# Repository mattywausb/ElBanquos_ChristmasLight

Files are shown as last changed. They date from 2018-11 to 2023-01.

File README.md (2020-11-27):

# ElBanquos Christmas Lights
An Ardiuno project using Neopixels to create slowly changing christmas light pictures in my window.

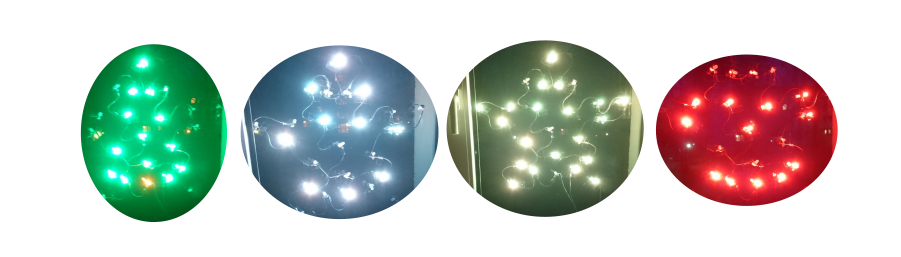
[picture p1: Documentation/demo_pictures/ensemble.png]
demo_ensemble some Impressions


## Whats the idea ?
I like to amaze people with riddles and small wonders. My favourinte approach is to establish little miracles that can only be noticed by people that observe the world carefully (its not for the 7x24 smartphone viewers). A long term vision was doing this with christmas decoration lights that change their pattern or picture without attracting attention by blinking or fast changing colors.

People should see the picture in the window and next time they come by will see another picture. They may wonder if they remembered it correctly or they might think that the guy behind the window changes it manually every day.  Only if they watch long enough they will see, how the pattern of light evolves slowly from one picture to another. Maybe they get curious enough to wait, what picture will come next and if they have seen them all.

Since there is not programmable christmas light chain in the stores, I have built my own.

### And the fireworks ?
While also enjoing it on new years eve I had the idea of switching the concept of slow animation to fast firework like effects to celebrate the new year. So I added a countdown clock and some fireworks animations. This mode can be activated for that special day.

## Features
* Easy maintainable programming of the light patterns
  * Picture is described on a logical lamp arrangemant. Translation to physical arrangement on the window is done at runtime.
  * Colorpalette helps to keep colors conistent an save memory.
  * Pixels can be distributed over multiple chains but appear in a linear adressspace
* Randomized transformation from one picture to the next
  * Random next picture
  * Random transformation order and timing of the pixels
  * Asynchronous and overlapping transformation of the pixels
  * Random hold time for one picture
* Fireworks for new years eve
  * countdown clock (mostly slow animated)
  * multiple simulations of fireworks
  * modularized and extendable implementation (add new ideas in 30 minutes)
* Testmodes to check 
  * correct pixel position
  * Pictures
  * Pixelfunction

## Whats in this repository
* Ardunio sketches for testing pixels and the final application
* Inkscape SVG with my light arrangement with 24 lamps 
* Fritzing circuit documentation
* Pictures of different assembly state phases to give you an idea how to build the chains
* [manual] (Documentation/manual_en.md) 

## Hardwarelist
* Arduino Uno board (or anything similar with 5 Digital Outs and 2 KByte SRAM)
* 24 Neopixel 8 mm throughole LED (or more)
* enough 3 core cable that is flexible and as thin as possible (I used old USB mouse wire, white = data, red+green=+5V, black+ground=gound)
* enough prototype PCB to cut the small connection pcb for every lamp
* 2 buttons
* whires 
* small breadboard (I used the Uno starterkit)
* "sugru" glue clay to protect the led mounting PCB's
* powert supply 5V / 1,5 A (for 24 pixels)
* scotchtape

## Softwarelist
* Arduino 
* Neo Pixel Library
* Fritzing (optional)
* Inkscape (optional)

## Tools
* Soldering iron 
* soldering holder
* wire stripper for very small diameters
* wire cutter
* pcb cutting tool (I used a saw)

## Main steps to build
* Assemble test circuit on the breadboard
* Test LED's on the breadboard (up to 8 when using 5V Adrunio board power)
* assemble every chain
  * Cut the small PCB boards (1 for the plug and 1 for every lamp)
  * Cut the mouse cable an remove isolations (1 for every lamp, 1st should be longer to reach from the window to the uno)
  * Create a 3 pin plug at one end of the long whire
  * Add pcb/Neopixel and continuation whire as often as needed (I made 3 chains of 8 pixels)
### Build effort
Initial time is needed to set up the uno and breadboard for testing.
After getting into a stable workflow it took me about 10 Minutes for every lamp (Cut pcb, cut cable, solder lamp, test). So all in all 240 Minutes for 24 Lamps (4 Hours) for assembling the chains. With better soldering technique and tools this might get better.

### Main material costs 43 EUR
* roundabout 25 Euro for 25 Neopixels (I killed one by testing with wrong polarity, thats why i have only 24)
* 8 Euros for the Sugru Glue Clay (1 Package with 3 portions)
* Old usb mouse cables should be available at every flea market
* My dedicated power supply const 10 Eur but mostly you already have some in stock

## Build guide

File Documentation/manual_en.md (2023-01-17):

# ElBanquos Christmas Lights - Manual

## Functions
The system contains multiple programs, that can be accessed by using the two buttons:
* Mode
* Step
 
Especially for assembly and installation there are various test programs to verify the electrical function and the correct arrangement of the lamps.

### Comprehensive mode change table:

|Current Mode|Press "Mode"|Press "Step"|Hold "Mode" Long|Hold "Step" Long|
|---|---|---|---|---|
|Show|>Countdown|>Transition||
|Transition|>Countdown|>Show||
|Countdown|>Fireworks|>Set Hour||
|Set Hour|Hour down|Hour up||>Set Minute|
|Set Minute|Minute down|Minute up||>Countdown|
|Fireworks|>Show|Next Effect|>Sensor Calibration||
|Sensor Calibration|>Show|>Tst: Placement|||
|Tst: Placement|>Tst: Palette|Switch Lamp group||
|Tst: Palette|>Tst: Pictures|Switch color of inner lamps||
|Tst: Picture|Previous Picture|Next Picture|>Tst: Fade Solo||
|Tst: Fade Solo|>Tst: Fade Ensemble|Next Lamp||
|Tst: Fade Ensemble|>Tst: Scaling|Next Lamp||
|Tst: Scaling Current|>Show|Add Lamp||

## Components and setup

* LED Light chains (currently 3 chains with 8 lamps each)
* controller board with
   * arduino
   * connectors for the light chains
   * Buttons
   * light sensor
   * light threshold control
   * USB Power cable Plug (Delivers power only, not data of arduino)
* USB Power Supply (5 V with at least 1.5 A)

This will not work with USB power supplies, which provide higher current only after been requested. (most USB power supplies don't care)

Maximum power consumption: LEDS (24x60mA) + Controllerboard (80mA) = 1.5 A 

## Setup
* Position light chains on the window
* connect light chains to controller board
* connect power

Never connect/disconnect light chains, when board has power. After disconnect from power, wait 1 Minute until connectin/disconnecting the light chains. This guarantees full discarge of the controller boards buffer 1000uF capacitor.

After connecting, check out the Testprogramm

## Mode descriptions

### Show Mode (Default Mode when switched on)
The show mode shows the static picture for a random number of seconds. After the wait time is over, a random new picture is determined and the program switches to transition mode.

Press MODE-> Countdown Mode

Press STEP-> Start transition to next picture in list

#### Daylight detection
The show mode uses a photocell to detect the ambient light situation. Only during low light, the show mode will choose one of the normal pictures. During "dailight", the show mode will activate one single lamp as an power indicator.

The threshold to determine "dailight" is set by the potentiometer. For adustment see Tst: Light sensor calibration.
When in daylight opreration, the sensor will be checked for a change every 60 seconds.

### Transition Mode
The Transition Mode modifies the lamps slowly in random order to transition to the next picture. After it is done, the mode switches to Show Mode.

Press MODE->  Countdown Mode

Press STEP-> Foreward transition to target picture an switch to show mode. 

### Countdown Mode
The Countdown Mode will display time of an internal clock and switch to fireworks automatically at 00:00. 
To understand the time display, see description "Hot the countdown time is displayed" below or check the table on the userpanel.

Press MODE-> Switch to Fireworks (Will be done automatically when reaching 00:00:00)

Press STEP-> Switch to Set Hour

### Set Hour Mode
The Set Hour Mode is used to set the hours left of the countdown. 

During the Set Hour Mode, the center lamp is **blinking red**

Press MODE-> 1 Hour Backward

Press STEP-> 1 Hour Forward

STEP Hold 2 sec (center lamp turns white) and release: Switch to Set Minute Mode

### Set Minute Mode
The Set Minute Mode is used to set the minutes left of the countdown. 
During the Set Hour Mode, the center lamp is **blinking blue**

Press MODE-> 1 Minute Backward

Press STEP-> 1 Minute Forward

Hold STEP for at least 2 sec (center lamp turns white): The release will start Clock (with 0 Seconds) and switch to Countdown Mode

### Fireworks Mode
The Fireworks Mode plays randomly chosen firework animations

Press MODE-> Switch to Show Mode

Press STEP-> Change to next fireworks pattern

MODE Hold 2 sec and release: Switch to Sensor Calibration

### Sensor Calibration
Sensor calibration activates most of the lamps in white and display the 
deviation between the current light sensor value and the threshold as a red lamp. 
The scale is formed by lamps E,10,K,11,A,1,G,2,8 (See user panel for lamp identification). The middle lamp on the star tip (A),
represents the current sensor value. The red indicated postion shows the current threshold, 
defined by the user setting. Placing the threshold to the left (E,10,K,11) defines the current
sensor value as lowlight. Setting it to the right (1,G,2,B) , defines the current sensor value as daylight.
One lamp stands for one histeresys interval. 
Value changes inside the histeresys interval will not change the current low/day state. 
To adjust the threshold for a spefic light level, wait for the level to come up and place the red dot 
in the center (A).

Press MODE -> Switch to Placement Test

Press STEP -> Switch to Show Mode

This calibration mode is only for easy search of the threshold.  The setting of the threshold is measured independently at every change of a picture, 
so adjustments are accepted, event  without using this mode.

Also be shure to place the sensor in a, it is not affected by the light of the christmas pictures. To help you
when tracing he path of the light, this mode switches most of the lights to white.
Placing some shade over the sensor, might be necessary. If the light of the pictures can reach the sensor,
some pitures might be bright enough to trigger the day mode.

### Placement Test
The placement test shows a rainbow color pattern on the different groups of lamps:

Press MODE-> Switch to Palette Test

Press STEP-> Switch to next group

The groups are:
* Chain identification: Three lamps in the center should be red,green,blue from left to right (if not you might have swapped cables when plugging)
* outer Pentagon/Star tips: Red on 12 o'clock, going clockwise to yellow, green, cyan, blue
* Middle circle: Red on 12 o'clock, going clockwise to yellow, green, cyan, blue (the 2nd lamp of a pair will be brighter)
* Inner Pentagon: Red on 6 o'clock, going clockwise to yellow, green, cyan, blue
* Bottom: Red, Middle yellow, "Head left" green, "Head right" blue

Should this be mixed up you need to check cables or placement of the lamps

### Palette Test
The palette test shows every palette color on a single lamp (Starting with lamp 6), and allows swithching through all palette colors on the inner ring and center lamp.

Press MODE-> Switch to Picture Test

Press STEP-> Switch inner lamps to next palette color

### Picture Test
The Picture Test shows a picture until it is stopped.

Press MODE-> Switch to Fade Solo Test

Press STEP-> Switch to next picture

Hold MODE for 2 Seconds -> Swith to Fade Solo Test

### Fade Solo Test
The Fade Solo Test fades one lamp fading green value from 0 to 255. Should be used while assembling the chain, to test added lamps.

Press MODE-> Switch to Fade Ensemble Test

Press STEP-> Switch to next lamp in the physical chain

### Fade Ensemble Test
The Fade Ensemble Test lights all lamps in cyan and a selected lamp with a fading red. Should be used while assembling the chain, to approve conductivity.

Press MODE-> Switch to Scaling Test

Press STEP-> Switch to next lamp in physical chain

### Scaling Current Test
The scaling current test lights lamps in with fading white, starting with one lamp. 
Should be used to check, if assemble cables and power supply will provide enough current. 
When all lamps are running, you have reached the highest power consumption possible. 
Fading must still be smooth and steady on all lamps an the should be no change in the white color. 
(When white is getting warmer, this indicates unsufficient power)

Press MODE-> Switch to Show Mode

Press STEP-> Add next lamp in physical chain.

# How the countdown time is displayed
The time display is designed to appear very static and add more movement, the nearer the time is to 00:00 resulting in a 1 Minute Countdown at 23:59.
It uses color and positions to symbolize the time as follows:

* Outer star points = Hours
* middle led Circle = Minute 0-58, Seconds of Minute 59
* inner 5 led circle = seconds (only for hour 23)
* center light = seconds (for hour 18 to 22)

In general colors transistion from blue/ green over white to orange/red, so red is always the last color before a change to a next element.
The minute ring displays "unused" minute lamps in yellow and used minute lamps in blue, changing the color of the current lamp accordingly to the upper schema.

The 5 hour lamps will light as follows (going backwards)
* 23:00 - all off
* 20:00 - 3 red 2 off
* 18:00 - all red
* 15:00 - 3 orange 2 red
* 13:00 - all orange
* 12:00	- all yellow
* 11:00 - all green
* 10:00 - all cyan
* 8:00 -  2 blue 3 cyan
* 5:00 - all blue
* 1:00 - 1 blue
* 0:00 - 2 pink lamps on the bottom (but normally here is the fireworks to see)

The minute lamps have some easy to recognize  positions/color as follows:
00 - all yellow
15 - 3rd right white
30 - bottom middle white
45 - 3rd left white

# Mode indication on the built in LED
The built in LED should not be visible in the final casing, but can be helpful during development:

* Show Mode: OFF
* Transition running: ON
* Countdown Mode: OFF
* Set Hour Mode: Blinking 2 per Second
* Set Minute Mode: Blinking 4 per Second
* Fireworks Mode: ON in show pause, OFF during running pattern
* All Tests: OFF

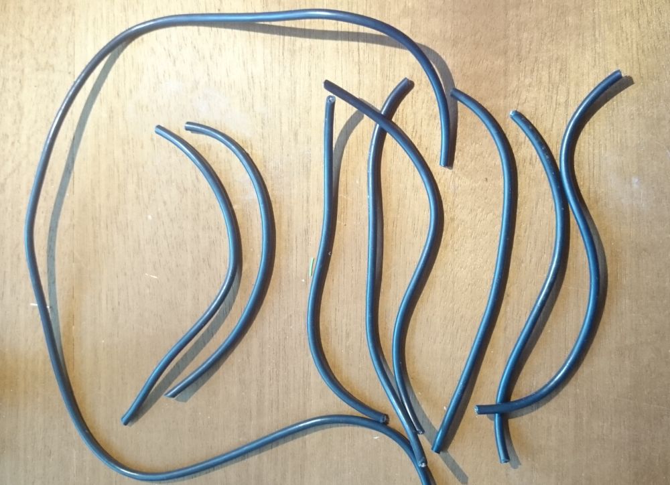
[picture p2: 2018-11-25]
Documentation/build_pictures/03_cutted_wires.jpg

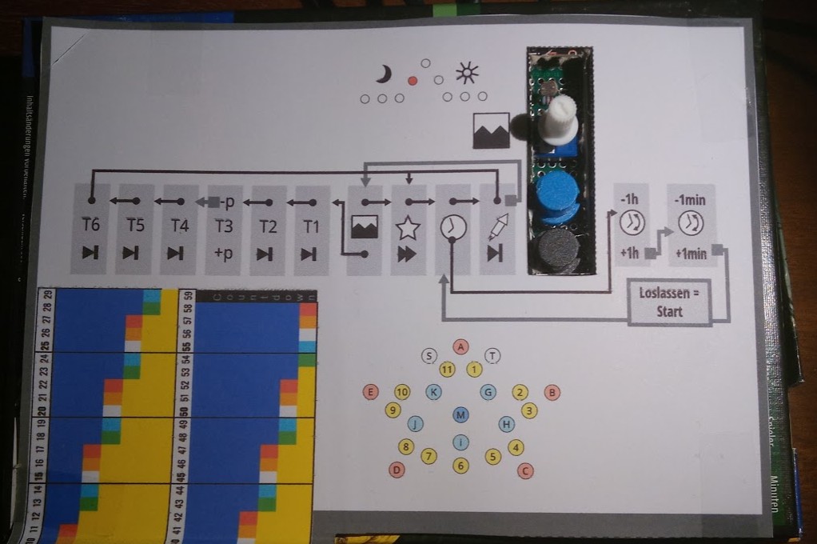
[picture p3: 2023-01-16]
Documentation/build_pictures/19_Controller_casing_and_userpanel.jpg

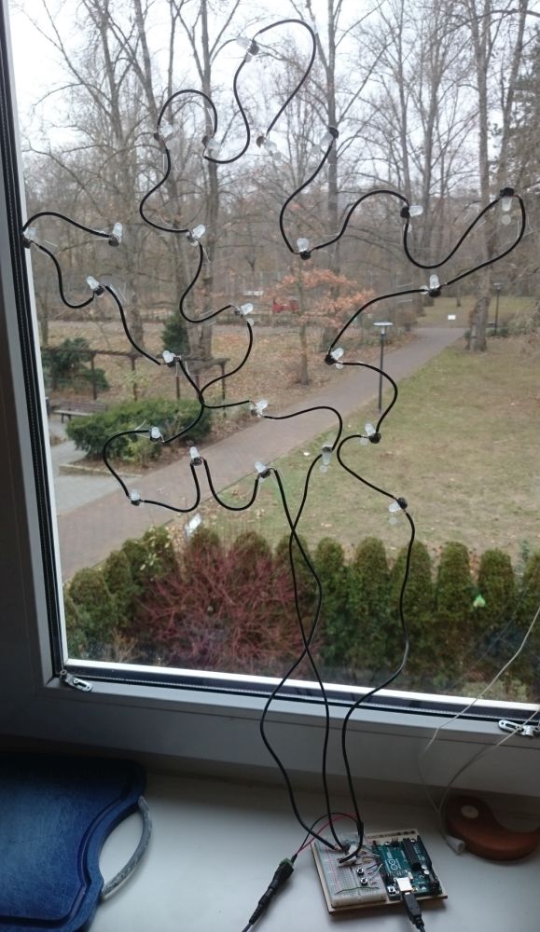
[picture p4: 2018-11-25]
Documentation/build_pictures/00_the_full_picture.jpg

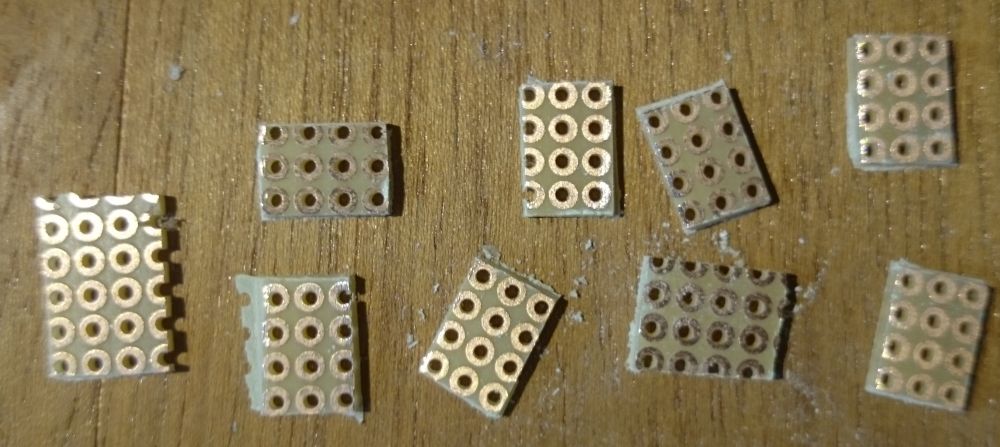
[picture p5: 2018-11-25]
Documentation/build_pictures/01_prototyp_pcb_cuts.jpg

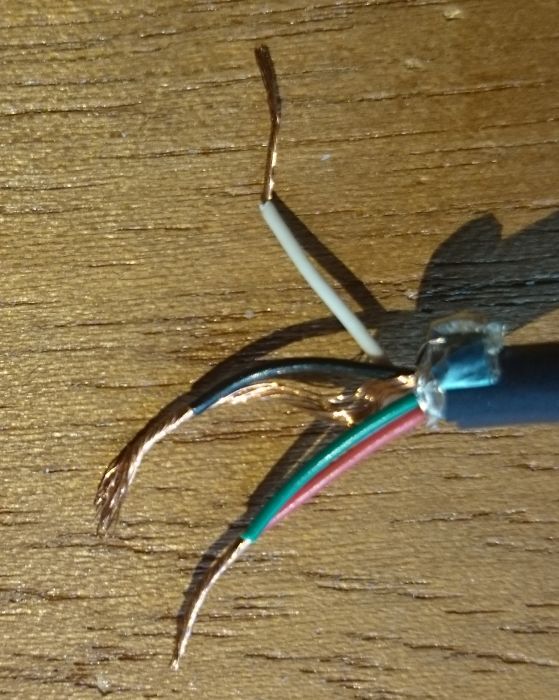
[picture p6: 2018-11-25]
Documentation/build_pictures/04_wire_union.jpg

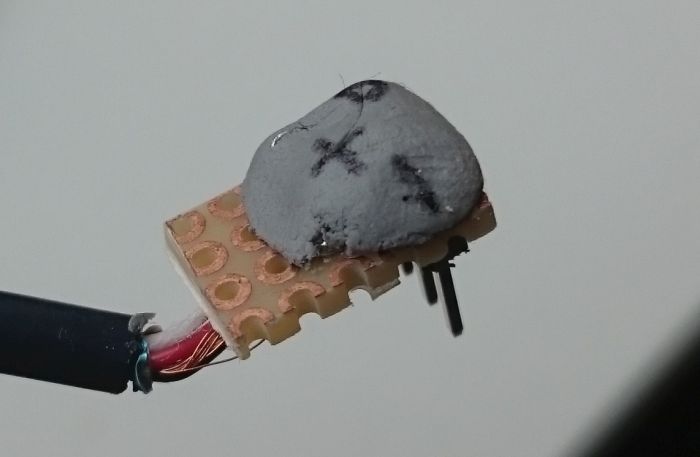
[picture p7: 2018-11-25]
Documentation/build_pictures/14_cable_plug_b.jpg

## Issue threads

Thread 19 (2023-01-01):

Mode indication for time setting on the lamps

mattywausb, 2023-01-01:
Currently indication is only on the built in LED, wich will not be visibile, when building a complete case

Closed 2023-01-16.

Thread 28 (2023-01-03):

Flip Buttons in SENSOR Calibration ("Mode" should switch to SHOW Mode and step to the other tests)

mattywausb, 2023-01-03:

mattywausb, 2023-01-03:
Changed code already to match with button panel, but is not tested

Closed 2023-01-16.

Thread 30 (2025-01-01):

Change Time modification button functions to prevent accidential hour change

mattywausb, 2025-01-01:
To resynchronize the clock you should Not need to Go through the hour modification mode.

New behaviour:
- Clock mode - B Button click > minute change : B Button hold release > start seconds at Zero
- minute change: B Button click > minute +1, A Button click> minute -1, A Button hold release > hour change, B Button hold release > start seconds at Zero
- hour change: A Button click> hour -1, B button click> hour +1, B Button hold release > minute change
- Time display for hour 0 and minute > 0: pink stars

- [ ] adapted manual de
- [ ] adapted manual en
- [ ] changed code about button assignment
- [ ] changed code about display of hour 0
- [ ] changed colour schema hint card
- [ ] printed and mounted

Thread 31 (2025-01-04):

Randomize change better

mattywausb, 2025-01-04:
Current method leads to predictable final sequencees.

High memory, fast method:
Determine and store random sequence for all lamps involved(needs 24 bytes) and process this list

New low memory method:
- count number of moves needed. Exchange, on only, off only, Colour swap;
- determine random number 0 to changemax
- walk through lamps and decrease number for every lamp that needs a change.
- initiatel transition of lamp when number reaches zero.

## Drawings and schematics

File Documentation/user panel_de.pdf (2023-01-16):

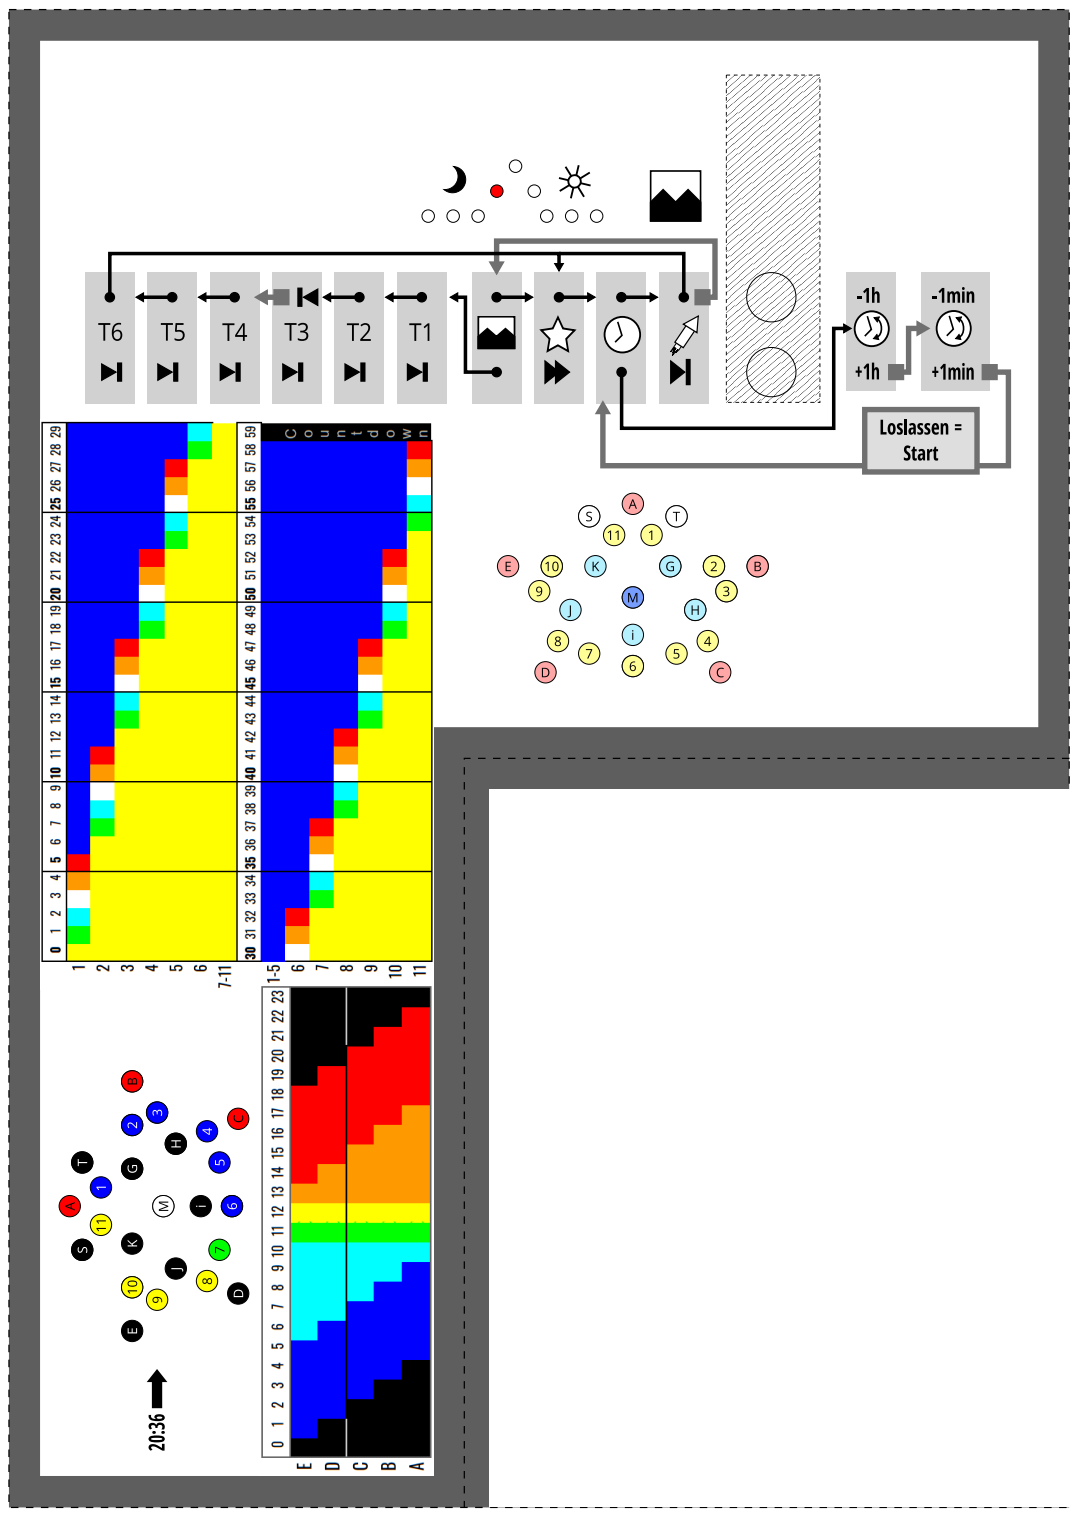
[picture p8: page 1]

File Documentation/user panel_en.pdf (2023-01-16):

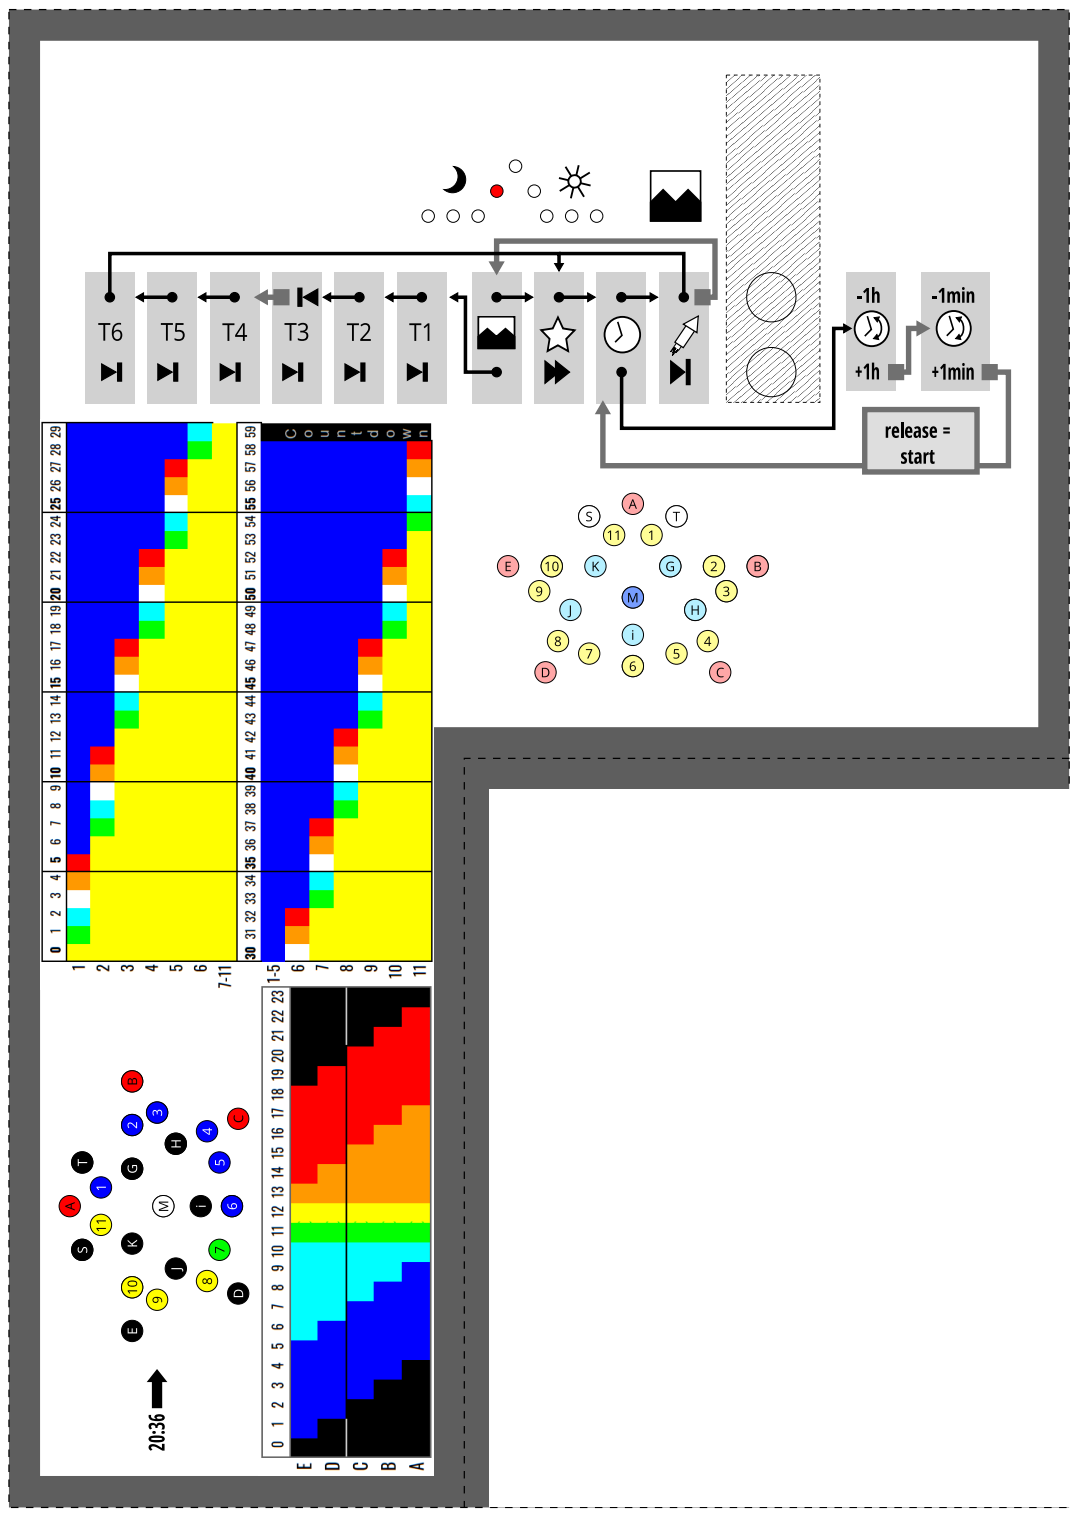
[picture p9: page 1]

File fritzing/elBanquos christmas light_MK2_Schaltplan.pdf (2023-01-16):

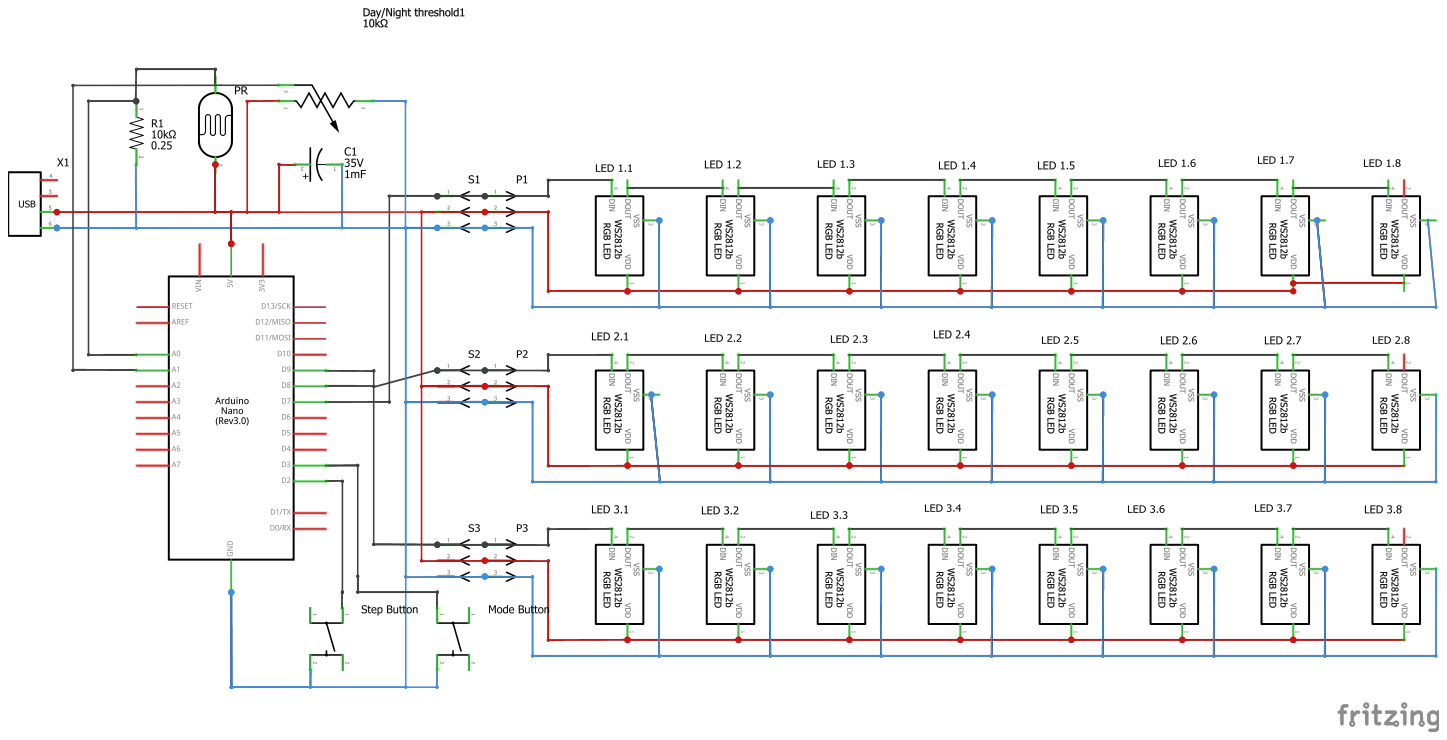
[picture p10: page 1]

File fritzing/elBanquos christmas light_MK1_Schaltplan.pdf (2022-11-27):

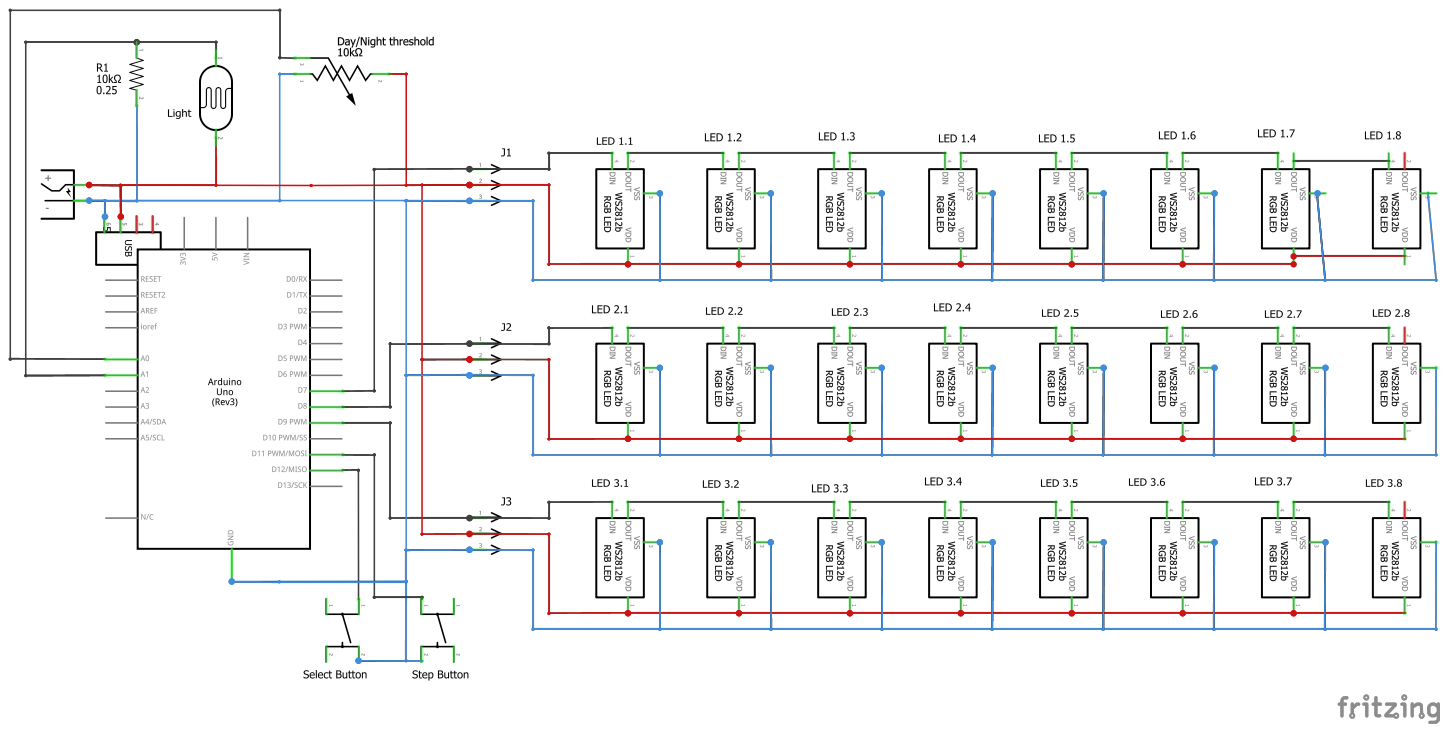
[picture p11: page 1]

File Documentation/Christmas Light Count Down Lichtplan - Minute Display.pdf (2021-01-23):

0 1 2 3 4 5 6 7 8 9 10 11 12 13 14 15 16 17 18 19 20 21 22 23 0 1 2 3 4 5 6 7 8 9

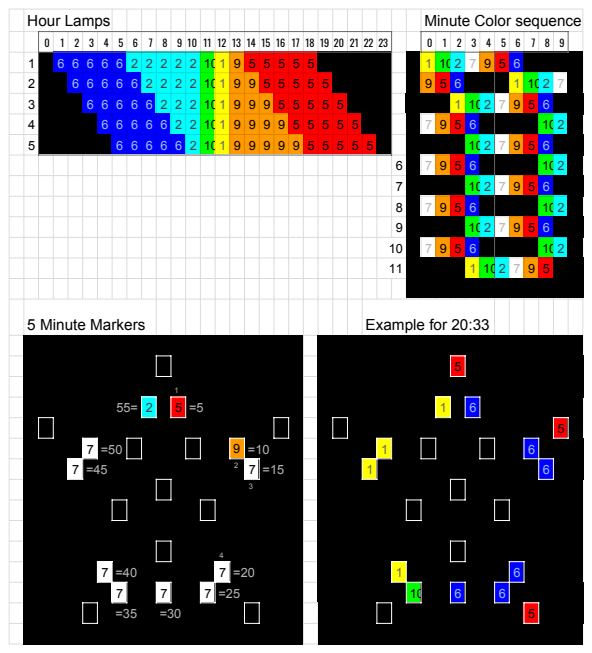
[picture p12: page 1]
Hour Lamps; Minute Color sequence; 5 Minute Markers; Example for 20:33

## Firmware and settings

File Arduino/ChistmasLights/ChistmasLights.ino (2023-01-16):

#include "picturelamp.h"
#include "mainSettings.h"
#include "particle.h"


#ifdef TRACE_ON
//#define TRACE_TRANSITION
#define TRACE_PICTURES
//#define ENTER_TESTMODE_IMMEDIATLY
//#define ENTER_CALIBRATION_IMMEDIATLY
#define ENTER_FIREWORKS_IMMEDIATLY
#define TRACE_MODES
#define DEBUG_ON
//#define TRACE_CALIBRATION
//#define TRACE_TIMING
//#define TRACE_CLOCK
//#define TRACE_CLOCK_TIME
#endif 

#define LAMP_COUNT 24

#define PARTICLE_COUNT 8


Particle g_firework_particle[PARTICLE_COUNT];


// TRANSITION_RYTHM_MINIMAL ms until next transition will be initiated 
// TRANSITION_RYTHM_VARIANCE maximum random addon to TRANSITION_RYTHM_MINIMAL 
// TRANSITION_DURATION_MINIMAL ms Duration of a single lamp transition 
// TRANSITION_DURATION_VARIANCE maximim random addon to TRANSITION_DURATION_MINIMAL
// SHOW_DURATION_MINIMAL ms until change to text picture will be triggered
// SHOW_DURATION_VARIANCE maximun random addon to SHOW_DURATION_MINIMAL


#ifndef DEBUG_ON
// normal timing setting
#define TRANSITION_RYTHM_MINIMAL 3000
#define TRANSITION_RYTHM_VARIANCE 5000
#define TRANSITION_DURATION_MINIMAL 6000
#define TRANSITION_DURATION_VARIANCE 4000
#define SHOW_DURATION_MINIMAL 400000  
#define SHOW_DURATION_VARIANCE 200000
#define SHOW_DAYLIGHT_CHECK_INTERVAL 60000

#else
// debug timing setting
#define TRANSITION_RYTHM_MINIMAL 1000
#define TRANSITION_RYTHM_VARIANCE 1000
#define TRANSITION_DURATION_MINIMAL 1500
#define TRANSITION_DURATION_VARIANCE 4000
#define SHOW_DURATION_MINIMAL 5000  
#define SHOW_DURATION_VARIANCE 7000
#define SHOW_DAYLIGHT_CHECK_INTERVAL 15000
#endif

#define BLEND_IN_DURATION 1500

#define LONG_PRESS_DURATION 1500

#define CLOCK_SECOND_LIVE_INTERVAL 60000

#define PICTURE_COUNT sizeof(g_pic_table)/sizeof(g_pic_table[0])

#define RANDOM_COLOR_INDEX_START 30


// Picture description
// number beginning at 30 define varaible palette. Defineing the group of same color in first digit and the color set to use in second
#define MAIN_STAR_LAMP_LIMIT 20
//                                         01 02 03 04 05  06 07 08 09 10  11 12 13 14 15 16 17 18 19 20  21 22 23 24

const byte pic_cassiopeia[24]  PROGMEM ={   0, 0, 0, 0, 6,  0, 6, 0, 0, 0,  0, 0, 0, 0, 0, 0, 0, 6, 6, 0,  0, 0, 0, 6}; // cassiopeia
const byte pic_star_uni[24]    PROGMEM ={   1, 1, 1, 1, 1,  1, 1, 1, 1, 1,  1, 1, 1, 1, 1, 1, 1, 1, 1, 1,  0, 0, 0, 0}; // star yellow
const byte pic_star_color[24]  PROGMEM ={  34,34,34,34,34, 44,44,44,44,44, 54,64,54,64,54,64,54,64,54,64,  0, 0, 0, 0}; // star_color
const byte pic_pentagons[24]   PROGMEM ={  31,31,31,31,31, 43,43,43,43,43,  0, 0, 0, 0, 0, 0, 0, 0, 0, 0,  0, 0, 0, 0}; // Pentagons
const byte pic_center_star[24] PROGMEM ={   0, 0, 0, 0, 0, 30,30,30,30,30,  0, 0, 0, 0, 0, 0, 0, 0, 0, 0,  0, 0, 0, 7}; // center star
const byte pic_gingerbread[24] PROGMEM ={  32,13,13,13,13, 13,13,13,13,13,  7, 7,13, 0,13, 0, 0,13, 0,13,  0,13,13,42}; // pic_gingerbread
const byte pic_angel[24]       PROGMEM ={   0, 2, 2, 2, 2,  2, 0, 0, 0, 0,  0, 0, 2, 2, 2, 2, 2, 2, 2, 2,  2, 2, 2, 0}; // Angle 
const byte pic_snow_man[24]    PROGMEM ={   0, 0, 7, 7, 0,  7, 0, 0, 0, 0,  0, 0, 0, 7, 7, 0, 0, 7, 7, 0,  7, 7, 7, 0}; // snow man
const byte pic_moon[24]        PROGMEM ={   0, 0, 7, 7, 0,  0, 0, 0, 0, 0, 12,12,12,12,12,12,12,12,12,12,  0, 0, 0, 5}; // Moon
const byte pic_flake_1[24]     PROGMEM ={   0, 0, 0, 0, 0, 30,30,30,30,30,  0,30, 0,30, 0,30, 0,30, 0,30,  0, 0, 0,40}; // flake_1
const byte pic_flake_2[24]     PROGMEM ={   0, 0, 0, 0, 0, 30,30,30,30,30, 30, 0,30, 0,30, 0,30, 0,30, 0,  0, 0, 0,40}; // flake_2
const byte pic_bell[24]        PROGMEM ={   0,12,12,12,12,  0, 0, 0, 0, 0,  0, 0, 0, 0,12,12,12,12, 0, 0,  1, 0, 0, 0}; // Bell
const byte pic_tree[24]        PROGMEM ={   3, 3, 3, 3, 3,  3, 0, 0, 0, 0,  3, 3, 0, 0, 3, 0, 0, 3, 0, 0,  4, 0, 0, 3}; // Tree
const byte pic_ichtys[24]      PROGMEM ={   6, 6, 0, 6, 6,  6, 0, 6, 0, 6,  0, 0, 0, 0, 6, 6, 0, 7, 6, 6,  0, 0, 6, 0}; // ychtis
const byte pic_3_wise[24]      PROGMEM ={  11, 0, 0, 0, 0,  7, 0, 0, 0, 0,  0, 0, 9, 9, 0, 0, 0, 0, 3, 3,  0, 0, 0,11}; // pic_3_wise
const byte pic_krippe[24]      PROGMEM ={   0, 9, 0, 0, 9,  0, 0, 9, 9, 0,  0, 0, 0, 0, 9, 0, 0, 9, 0, 0,  1, 0, 7, 9}; // krippe
const byte pic_half_moon[24]   PROGMEM ={   1, 0, 0, 1, 1,  0, 0, 0, 0, 0,  0, 1, 1, 1, 1, 1, 1, 1, 0, 0,  1, 0, 0, 0}; // half_moon
const byte pic_pyramid[24]     PROGMEM ={  12, 0, 0, 0, 0,  0, 0,12,12, 0,  0, 0, 0, 0, 0,12,12, 0, 0, 0,  0, 0, 0, 0}; // half_moon
const byte pic_fade_star[24]   PROGMEM ={   9, 9, 9, 9, 9,  7, 7, 7, 7, 7,  1, 0, 1, 0, 1, 0, 1, 0, 1, 0,  0, 0, 0, 5}; // fade star
const byte pic_fade_arrow[24]  PROGMEM ={   5, 9, 1, 1, 9,  7, 0, 8, 8, 0,  1, 1, 0, 0, 5, 0, 0, 5, 0, 0,  8, 0, 0, 9}; // fade arrow

//                                         01 02 03 04 05  06 07 08 09 10  11 12 13 14 15 16 17 18 19 20  21 22 23 24

//const byte pic_heart[24]     PROGMEM ={   0, 0, 5, 5, 0,  0, 0, 0, 0, 0,  0, 0, 5, 5, 5, 5, 5, 5, 5, 5,  5, 0, 0, 5}; // Heart



//const byte pic_######[24]      PROGMEM ={   0, 0, 0, 0, 0,  0, 0, 0, 0, 0,  0, 0, 0, 0, 0, 0, 0, 0, 0, 0,  0, 0, 0, 0}; //## #####

                                                     
const byte* const g_pic_table [] ={
                                   pic_star_uni,     
                                   pic_star_color,   
                                   pic_fade_star,     
                                   pic_flake_1,      
                                   pic_flake_2,      
                                   pic_center_star,  
                                   pic_pentagons,    
                                   pic_moon,         
                                   pic_gingerbread,  
                                   pic_angel,        
                                   pic_snow_man,     
                                   pic_bell,         
                                   pic_tree,         
                                   pic_fade_arrow,
                                   pic_3_wise,       
                                   pic_krippe,       
                                   pic_pyramid, 
                                   pic_half_moon,    
                                   pic_ichtys,       
                                   pic_cassiopeia  
                                   }; 

#define PICTURE_POINT(pic,lamp) pgm_read_byte_near(g_pic_table[pic]+lamp*sizeof(byte))

#define iRED 0
#define iGREEN 1
#define iBLUE 2

#define COLOR_IX_BROWN 4
#define COLOR_IX_ORANGE 9
#define COLOR_IX_RED 5
#define COLOR_IX_WHITE 7
#define COLOR_IX_YELLOW 1
#define COLOR_IX_BLUE 6

int g_color_palette[][3]={
//          {0  ,0  ,0  },    // 0 = black
          {0  ,0  ,0  },    // 0 = black
//          {1  ,0.65,0  },   // 1 = yellow
          {10000  ,6500,0  },   // 1 = yellow
//          {0  ,0.8  ,0.8  },// 2 = cyan
          {0  ,8000  ,8000  },// 2 = cyan
//          {0  ,0.5,0.08},   // 3 = mid green
          {0  ,3500,250},     // 3 = mid green
//          {0.2,0.1,0 },     // 4 = dark brown
          {2000,1000,0 },     // 4 = dark brown
//          {1,0.0,0  },      // 5 = red
          {10000,0,0  },      // 5 = red
//          {0  ,0  ,0.8},    // 6 = blue
          {0  ,0  ,8000},    // 6 = blue
//          {1  ,1  ,1  },    // 7 = white
          {10000  ,10000  ,10000  },    // 7 = white
//          {0.8  ,0  ,0.8  },// 8 = pink
          {8000  ,0  ,8000  },// 8 = pink
//          {1  ,0.3,0  },    // 9 = orange
          {10000  ,3000,0  },    // 9 = orange
//          {0  ,1  ,0  },    // 10 (A)= bright green
          {0  ,10000  ,0  },    // 10 (A)= bright green
//          {0.1  ,0  ,0.75 },// 11 (B)= dark purple
          {1000  ,0  ,7000 },// 11 (B)= dark purple
//          {1, 0.45,0},      // 12 (C)= gold
          {10000, 4500,0},      // 12 (C)= gold
//          {0.5,0.0,0.07},   // 13 (D)= low pastell red
          {5000,0,700},   // 13 (D)= low pastell red
};

#define COLOR_PALETTE_COUNT 14

//                       GFEDCBA9, 87654321 
byte g_color_set[] =  { B00000011,B10110011,  // 0 = all saturated full colors
                        B00001000,B01000010,  // 1 = Gold, White, Cyan
                        B00000011,B10100011,  // 2 = all saturated full colors except red
                        B00000010,B10110100,  // 3 = Green, pink, blue,red,mid green
                        B00000010,B00110001,  // 4 = Green,, blue,red,yellow
                                       };
#define COLOR_SET_COUNT sizeof(g_color_set)/sizeof(g_color_set[0])/2;


byte g_random_color_map[4]={0,0,0,0};    // this is used to map from group to randomly chosen color
#define RANDOM_COLOR_MAP_COUNT sizeof(g_random_color_map)/sizeof(g_random_color_map[0])

PictureLamp g_picture_lamp[LAMP_COUNT];

unsigned long g_picture_start_time=0;
unsigned long g_picture_duration_time=5000;
unsigned long g_transition_start_time=0;
unsigned long g_transition_follow_up_duration=5000;


byte g_pic_index=0; //
bool g_in_daylight=false;

#define PICTURE_HISTORY_COUNT 4
byte g_picture_history [PICTURE_HISTORY_COUNT];
byte g_picture_history_next_entry_index=0;

// lamp path buffers

#define LAMP_PATH_MAX_STEPS 10
#define LAMP_PATH_BUFFER_LENGTH LAMP_PATH_MAX_STEPS*2+1
#define LAMP_PATH_BANK_COUNT 5
byte g_lamp_path_buffer[LAMP_PATH_BANK_COUNT][LAMP_PATH_BUFFER_LENGTH];

// lamp path to display calibration                      1  2 3  4 5  6 7  8 9  10
const byte lamp_path_for_calibration_scale[] PROGMEM ={ 10,20,3,11,6,12,4,13,7,255};  
#define CALIBRATION_SCALE_LAMP_COUNT 9
#define CALIBRATION_SCALE_CENTER_INDEX 4


/* Control */
enum PROCESS_MODES {
  SHOW_MODE, 
  TRANSITION_MODE,
  CLOCK_MODE,
  CLOCK_SET_HOUR_MODE,
  CLOCK_SET_MINUTE_MODE,
  FIREWORK_RUN,
  SENSOR_CALIBRATION,
  TEST_MODE_PLACEMENT,
  TEST_MODE_PALETTE,
  TEST_MODE_PICTURES,
  TEST_MODE_FADE_SOLO,
  TEST_MODE_FADE_IN_ENSEMBLE,
  TEST_MODE_SCALING,
};

PROCESS_MODES g_process_mode = SHOW_MODE; 

/* **************** setup ******************************* */

void setup() {
  #ifdef TRACE_ON 
    char compile_signature[] = "--- START (Build: " __DATE__ " " __TIME__ ") ---";   
    Serial.begin(9600);
    Serial.println(compile_signature); 
  #endif

  // Init all Pins and interfaces
  pinMode(LED_BUILTIN, OUTPUT);
  output_setup();
  input_setup();

   for(int i=0;i<LAMP_COUNT;i++)  /* Initialize all lamps */
   {
         g_picture_lamp[i].setCurrentColor(0,0.3,0);
         g_picture_lamp[i].updateOutput(i);
   }
   output_show();
   
  // wait for chains to power up completetly
  delay(1500);

  // Init the pciture Lamps
  for(int i=0;i<LAMP_COUNT;i++)  /* Initialize all lamps */
  {
         g_picture_lamp[i].setCurrentColor(0,0,0);
         g_picture_lamp[i].updateOutput(i);
  }
   output_show();
   
  // Init the first picture 
  for (int i=0;i<PICTURE_HISTORY_COUNT;i++) {
      g_picture_history[i]=0;
  };
  randomSeed(analogRead(INPUT_ANALOG_PORT_SENSOR)); // 

  // provide picture lamp array to the particle engine 
  for(int p=0;p<PARTICLE_COUNT;p++)
        g_firework_particle[p].init(g_picture_lamp);

  // switch to normal operation
  #ifdef ENTER_FIREWORKS_IMMEDIATLY
    enter_FIREWORK_RUN();
    return;
  #endif
  #ifdef ENTER_CALIBRATION_IMMEDIATLY
    enter_SENSOR_CALIBRATION();
    return;
  #endif
  #ifdef ENTER_TESTMODE_IMMEDIATLY
    enter_TEST_MODE_PICTURES();
    return;
  #endif
  enter_SHOW_MODE();
}

/* **************** LOOP ******************************* */
void loop() 
{
   input_switches_scan_tick();

   switch(g_process_mode) {
    case SHOW_MODE: process_SHOW_MODE();break;
    case TRANSITION_MODE:process_TRANSITION_MODE();break;
    case CLOCK_MODE:process_CLOCK_MODE();break;
    case CLOCK_SET_HOUR_MODE:process_CLOCK_SET_MODE();break;
    case CLOCK_SET_MINUTE_MODE:process_CLOCK_SET_MODE();break;
    case FIREWORK_RUN:process_FIREWORK_RUN();break;
    case SENSOR_CALIBRATION:process_SENSOR_CALIBRATION();break;
    case TEST_MODE_PLACEMENT:process_TEST_MODE_PLACEMENT();break;
    case TEST_MODE_PALETTE:process_TEST_MODE_PALETTE();break;
    case TEST_MODE_PICTURES:process_TEST_MODE_PICTURES();break;
    case TEST_MODE_FADE_SOLO:process_TEST_MODE_FADE_SOLO();break;
    case TEST_MODE_FADE_IN_ENSEMBLE:process_TEST_MODE_FADE_IN_ENSEMBLE();break;
    case TEST_MODE_SCALING: process_TEST_MODE_SCALING();break;
   } // switch
}

/* ========= SHOW_MODE ======== */
void enter_SHOW_MODE()
{
    #ifdef TRACE_MODES
      Serial.print(F("#SHOW_MODE: "));
      Serial.print(freeMemory());
      Serial.print(F(" bytes free memory. "));
      Serial.print(millis()/1000);
      Serial.println(F(" seconds uptime"));
    #endif

    
    if(g_process_mode!=TRANSITION_MODE) {  // When not coming from transition,
        for(int i=0;i<LAMP_COUNT;i++)  // Initialize all lamps to black
        {
         g_picture_lamp[i].setCurrentColor(0,0,0);
         g_picture_lamp[i].updateOutput(i);
         g_picture_lamp[i].startTransition(BLEND_IN_DURATION);  
        }
        output_show();
        g_pic_index=random(PICTURE_COUNT); // chose a picture regardless of the history
        store_picture_in_history(g_pic_index);
        enter_TRANSITION_MODE(); // this will blend in the chosen picture
        return;
    } else { 
            // immediate end of transition (Picture will fully displayed)
            for(int i=0;i<LAMP_COUNT;i++) 
                  {
                     g_picture_lamp[i].endTransition();
                     g_picture_lamp[i].updateOutput(i);
                   }
            output_show();
    }


    g_process_mode=SHOW_MODE;
    input_IgnoreUntilRelease();
    digitalWrite(LED_BUILTIN, false);
    g_picture_start_time=millis();
    if(!g_in_daylight)    g_picture_duration_time=SHOW_DURATION_MINIMAL+random(SHOW_DURATION_VARIANCE);
    else g_picture_duration_time=SHOW_DAYLIGHT_CHECK_INTERVAL;
    #ifdef TRACE_TIMING
      Serial.print(F("TRACE_TIMING:g_picture_duration_time="));
      Serial.println(g_picture_duration_time/1000);
    #endif
}

void process_SHOW_MODE()
{
    if(input_modeGotPressed()) 
    {
      enter_CLOCK_MODE();
      return;
    }
    
    if(input_stepGotPressed()) {    // Switch to next picture in list
      if(++g_pic_index>=PICTURE_COUNT) g_pic_index=0;  // Switch to next picture in list
      enter_TRANSITION_MODE();
      return;
    }

     if(millis()-g_picture_start_time > g_picture_duration_time) {  // start transition to a random picture 
      g_pic_index=255;
     
      while (g_pic_index==255)
      {
        g_pic_index=random(PICTURE_COUNT);
        for(byte i=0;i<PICTURE_HISTORY_COUNT;i++) { // check history
          if(g_pic_index==g_picture_history[i]) 
          { 
            g_pic_index=255;  //bad choice
            break;
          }
        }
      }
      
      store_picture_in_history(g_pic_index);
      enter_TRANSITION_MODE();
      return;  
     }
}

/* ========= TRANSITION_MODE ======== */

void enter_TRANSITION_MODE()
{
    #ifdef TRACE_MODES
      Serial.print(F("#TRANSITION_MODE:start "));
      Serial.println(millis()/1000);
    #endif
    g_process_mode=TRANSITION_MODE;
    input_IgnoreUntilRelease();

    g_in_daylight=input_getDaylightState();
    if(!g_in_daylight) { // normal operation
        set_target_picture(g_pic_index);
    } else set_daylight_target_picture();
    digitalWrite(LED_BUILTIN, true);


}

void process_TRANSITION_MODE()
{
    int transitionsRunningCount=0;

    if(input_modeGotPressed()) 
    {
      enter_CLOCK_MODE();
      return;
    }

    if(input_stepGotPressed()){   // Fast foreward the transistion 
       enter_SHOW_MODE();
       return;
    }
    
    // update all transitioning lights
    for(int i=0;i<LAMP_COUNT;i++) 
    {
      if(g_picture_lamp[i].is_in_transition()) 
      {
        g_picture_lamp[i].updateOutput(i);
        transitionsRunningCount++;
      }
    }
    output_show();

    // Order next transitions
    if(transitionsRunningCount<1 || millis()-g_transition_start_time>g_transition_follow_up_duration) 
    {
      triggerNextTransition();
      if ( getTransitionsRunningCount()==0 ) enter_SHOW_MODE();
      #ifdef TRACE_TRANSITION
        Serial.print(F("TRACE_TRANSITION::transitions running: "));
        Serial.println(getTransitionsRunningCount());
      #endif
      g_transition_start_time=millis();
      g_transition_follow_up_duration=TRANSITION_RYTHM_MINIMAL+random(TRANSITION_RYTHM_VARIANCE);

    }
    #ifdef TRACE_TRANSITION 
    //delay(500);
    #endif
}



/* ----- internal picture presentation helpers --------- */

/* check for random colors, make a unique wish and provide it in random_color_map
 */

void populate_random_color_map(int picture_index){
  byte color_list[16];
  byte color_list_length=0;
  
  for(int i=0;i<RANDOM_COLOR_MAP_COUNT;i++) g_random_color_map[i]=0;  // Reset color map
  
  for (int lmp=0;lmp<LAMP_COUNT;lmp++) {
     byte p_index=PICTURE_POINT(picture_index,lmp);
     if(p_index>=RANDOM_COLOR_INDEX_START) {  // Lamp has random color declaration
        int map_slot=(p_index-RANDOM_COLOR_INDEX_START)/10;
        
        if(g_random_color_map[map_slot]==0) {  // only choose a color for a mapslot, if not already done
          byte color_set_index=p_index%10;
          #ifdef TRACE_RND_COL_GEN
            Serial.print(F("#TRACE_RND_COL_GEN: Choosing for "));
            Serial.print(map_slot);
            Serial.print(F(" from color set "));
            Serial.println(color_set_index);
          #endif  
          // Convert bitmap of color set into list of palette indexes
          color_list_length=0;
          for(int byteindex=0;byteindex<2;byteindex++) {
            byte color_set_bitmap=g_color_set[color_set_index*2+byteindex];
            for (int bitindex=0;bitindex<8;bitindex++) {
              if(bitRead(color_set_bitmap,bitindex)) {  
                color_list[color_list_length]=bitindex+((1-byteindex)*8)+1;
                  #ifdef TRACE_RND_COL_GEN
                    Serial.println(color_list[color_list_length]);
                  #endif  
                color_list_length++;
                }
             } // Loop over bits
          } // Loop over bytes

          // Chose random element of the list and check if color already used, if not traverse until you find one
          byte choice=random(color_list_length);
          for(int check=0;check<color_list_length ;check++) { // only try until traversing full list
              int m=0;
              for(;m<RANDOM_COLOR_MAP_COUNT;m++) {
                if(g_random_color_map[m]==color_list[choice]) break; 
              }
              if(m>=RANDOM_COLOR_MAP_COUNT) {  // This color is not used yet
                g_random_color_map[m]=color_list[choice];
                break; // leave the check loop
              }
              if(++choice >= color_list_length) choice=0;
          } // end check loop
          if(g_random_color_map[map_slot]==0) g_random_color_map[map_slot]=color_list[choice]; // if decision could not be made use first idea
          #ifdef TRACE_RND_COL_GEN
            Serial.print(F("#TRACE_RND_COL_GEN: Final choice is "));
            Serial.println(g_random_color_map[map_slot]);
          #endif 
        } // end map slot is empty
        
     } // end this is a random color entry
  } // loop over all lamps in the picture
}

byte get_mapped_color_number(byte pic_color_entry) {
  if(pic_color_entry<RANDOM_COLOR_INDEX_START) return pic_color_entry;
  byte map_slot=(pic_color_entry-RANDOM_COLOR_INDEX_START)/10;
  return g_random_color_map[map_slot];
}

/* set_picture
 *  Orders all lamp objects to go to the defined picuture
 */
void set_picture(int picture_index)
{
#ifdef TRACE_PICTURES
  Serial.print(F("TRACE_PICTURES::set_picture"));
  Serial.println(picture_index);
#endif
  populate_random_color_map(picture_index);
  for (int i=0;i<LAMP_COUNT;i++) {
     byte c_index=get_mapped_color_number(PICTURE_POINT(picture_index,i));
     g_picture_lamp[i].setCurrentColor_int(g_color_palette[c_index][iRED],g_color_palette[c_index][iGREEN],g_color_palette[c_index][iBLUE]);
     g_picture_lamp[i].updateOutput(i);
  }
}

/* Set Target Picture
 *  Sets the target values of all lamp to the picture defined by the index 
 */
void set_target_picture(int picture_index)
{
#ifdef TRACE_PICTURES
  Serial.print(F("TRACE_PICTURES::set_target_picture "));
  Serial.println(picture_index);
#endif
  populate_random_color_map(picture_index);
  for (int i=0;i<LAMP_COUNT;i++) {
     byte  c_index=get_mapped_color_number(PICTURE_POINT(picture_index,i));
     g_picture_lamp[i].setTargetColor_int(g_color_palette[c_index][iRED],g_color_palette[c_index][iGREEN],g_color_palette[c_index][iBLUE]);
  }
}

/* Set dailight Picture
 *  Sets the target values of all lamp to the energy saving dailight picture
 */

void set_daylight_target_picture(){
    #ifdef TRACE_PICTURES 
     Serial.println(F("TRACE_PICTURES::set_daylight_target_picture"));
    #endif
    for (int i=0;i<LAMP_COUNT;i++) { // set all to black
       g_picture_lamp[i].setTargetColor_int(0,0,0);
    }
    g_picture_lamp[20].setTargetColor_int(g_color_palette[COLOR_IX_BROWN][iRED],g_color_palette[COLOR_IX_BROWN][iGREEN],g_color_palette[COLOR_IX_BROWN][iBLUE]); // set one lamp to brown
}

void store_picture_in_history(byte pic_index) {
      g_picture_history[g_picture_history_next_entry_index]=pic_index; // put choice into the history
      if(++g_picture_history_next_entry_index>=PICTURE_HISTORY_COUNT) g_picture_history_next_entry_index=0;
}
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

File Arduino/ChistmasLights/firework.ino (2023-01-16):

#include "particle.h"

#ifdef TRACE_ON
//#define TRACE_FIREWORK
//#define TRACE_FIREWORK_HIGH

#endif 

#define FW_MAX_RUNTIME 3600000     // 1 Hours 
//#define FW_MAX_RUNTIME 60000     // 1 Minute

#define FW_SHOW_TYPE_COUNT 7

/*  ===== Description of the Firework Implementation pattern =======
For Implementing the firework shows I use multiple layers of abstraction. 
Lamp Object = Has the ability to fade from one color / brightness to another in a defined time 
Path = A pre defined chain of Lamp objects, defining a stay duration and a fade duratoin
Particle = A virtual lamp trigger, "ignightin lamps" while running along a path
show = A set of instructions, starting particles at the right time for the effect

Show initiation
Every show has its own initiation phase, to load its needed paths into the global lamp_path_buffer.
By setting the g_fw_show_shot_limit and counting the the number of particles fired in g_fw_show_shot, the show defines 
it's ending criteria. Like in "Nature" this limit an be randomized in a approriate range

The main loop 
- first checks, if a show needs to be started, and will chose a new show
- Checks it the show is over by comparing number of shots and the limit
- Checks if the next particle has to be emitted according to g_picture_start_time and  g_picture_duration_time 
  and calls the particle emmitter function for the running show
- Let all active particles calculate their progress (wich might trigger new lamps)
- Let all active lamps calculate their progress
- Update the Lamps

Partice emitter functions
Every show has a particle emitter function, that will be called by the main loop, when the time for a new partice has been reached.
The emitter function needs to
- Determine the particles to start, depending on the g_fw_show_shot value
- increment g_fw_show_shot
- set g_picture_duration_time to the duration until the next particle has to be triggered

*/


                                                                      // lamp number and timing(4 bit fade, 4 bit stay duration)  for particle
                                                                      // fade=0-F = 10-535ms 35ms steps
                                                                      // framelength=0-F = 10-535ms 35ms steps  
                                                                      // Lamp 255 = Endmarker
//                                1       2       3       4       6       6       7       8        9      10
const byte fw_path_long_arc[] PROGMEM ={ 9,0x51,18,0x51, 2,0x62, 3,0x73,12,0x73,13,0x62, 14,0x62,255};   
const byte fw_path_central_arc[] PROGMEM ={ 21,0x51,1,0x62, 24,0x62, 3,0x73,18,0x73,9,0x62,255}; 

const byte fw_path_beam_3h[] PROGMEM ={ 4,0xc2,13,0xa2, 7,0x62,255};   
const byte fw_path_beam_5h[] PROGMEM ={ 5,0xc2,15,0xa2, 8,0x62,255};   
const byte fw_path_beam_7h[] PROGMEM ={ 1,0xc2,17,0xa2, 9,0x62,255};   
const byte fw_path_beam_9h[] PROGMEM ={ 2,0xc2,19,0xa2,10,0x62,255};  
const byte fw_path_beam_0h[] PROGMEM ={ 3,0xc2,11,0xa2, 6,0x62,255};
   
const byte fw_path_circle[] PROGMEM ={ 22,0xc0,4,0xf1,2,0xc0,11,0xb0, 20,0xe1,24,0xd0,19,0xc1,12,0xb0,255};   // stay duration 0 = light all lamps instanty
//const byte fw_path_circle[] PROGMEM ={ 22,0xc0,4,0xf0,2,0xc0,11,0xb0, 20,0xe0,24,0xd0,19,0xc0,12,0xb0,255};   // stay duration 0 = light all lamps instanty
const byte fw_path_straigth_accellerating[] PROGMEM ={ 9,0x53,18,0x42, 2,0x21, 3,0x11,11,0x11,6,0x11, 255};   
const byte fw_path_straigth_decellerating[] PROGMEM ={ 9,0x32,18,0x32, 2,0x43, 3,0x43,11,0x54,6,0x54, 255};  
const byte fw_path_peak_explode_1[] PROGMEM ={ 22,0xd0,12,0xcd, 20,0xa0, 3,0xb0, 255};  
const byte fw_path_peak_explode_2[] PROGMEM ={ 22,0xa0,23,0xdd, 20,0xb0, 13,0xc0, 255};  
const byte fw_path_middle_up[] PROGMEM ={ 21,0x32,1,0x22, 24,0x43, 6,0x43, 255};  


byte g_next_free_particle=0;
byte g_fw_show_type=0;
int g_fw_show_shot=0; 
int g_fw_show_shot_limit=0; 
float  g_fw_main_color;
boolean g_mirror=false;
byte g_prev_fw_show_type=0;

// interval map that is used to create an uneven probabilty pattern. longer interval = higher probability
const byte show_probabilty_hitrange[] PROGMEM = {15,  // Sparkle left right  (15%)
                                                 35,  // Single random rockets (20%)
                                                 43,  // sunflower (8%)
                                                 55,  // Joker (12%)
                                                 75,  // roman lights (20%)
                                                 100};  // Glitter bomb (25%)





/* ========= FIREWORK_RUN ======== */

void enter_FIREWORK_RUN() 
{
    #ifdef TRACE_MODES
      Serial.print(F("#FIREWORK_RUN: "));
      Serial.print(freeMemory());
      Serial.println(F(" bytes free memory"));
    #endif
    delay(500);
    g_process_mode=FIREWORK_RUN;
    digitalWrite(LED_BUILTIN, false);
    input_IgnoreUntilRelease();
    for(int i=0;i<LAMP_COUNT;i++)  /* Initialize all lamps */
    {
         g_picture_lamp[i].setTargetColor(0,0,0);
         g_picture_lamp[i].endTransition();
         g_picture_lamp[i].updateOutput(i);
       }

    g_picture_start_time=millis();
    g_transition_follow_up_duration=millis();  // we use this global to track the overall runtime
    g_picture_duration_time=0;
    g_next_free_particle=0;
    for(int p=0;p<PARTICLE_COUNT;p++)
        g_firework_particle[p].end();
    g_fw_show_type=3;  // start with sun
    fw_init_show();
}
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

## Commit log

2018-11-02 Test and circuit
    [elBanquos christmas light_MK1.fzz]
2018-11-24 Added buttons, refactored picturelamp to store values in scaled integer
2018-11-24 Corrected lamp numbering, bugfixed some pictures randomized transition timing
    [ChistmasLights.ino, output.ino, picturelamp.cpp]
2018-11-25 Updated circuit diagram with buttons and usb power principle
    [elBanquos christmas light_MK1.fzz]
2018-11-25 Randomized picture sequence, optimized button controls
2019-11-30 Added frame construction
2019-12-27 Issue#1 tested, Clock hour display trace test done
    [ChistmasLights.ino]
2019-12-27 Minute Presentation Trace Test done
2019-12-27 Second and final countdown trace tested
2019-12-28 added timer for fireworks
2019-12-28 Mockup led integrated, primitive fireparticle implemented
2019-12-30 bugfix of minute display
    [ChistmasLights.ino]
2019-12-30 Added 8 led strip to mockup
2019-12-30 bug fix of firewwirk pause, first good rockets
    [firework.ino, particle.cpp]
2020-11-27 #3 - ENter Testmode only after long select press from fireworks. Short Press goes to show mode Turn on Built_IN_LED during pause of fireworks
    [firework.ino]
2020-11-27 #5 fixed- Center Light now goes dark in minute 59
    [ChistmasLights.ino]
2020-11-27 Color correction for purple
    [ChistmasLights.ino]
2021-01-23 Added new pictures, and fixed #9
    [ChistmasLights.ino]
2021-01-23 Fixed faulty mode switches, changed start firework to sparkle
    [ChistmasLights.ino, firework.ino]
2021-01-24 Final new palette und randomizer
2021-01-24 Fixed transtion at 00:00
    [clock.ino]
2022-11-20 Added Light sensor and light sensor test sketch
    [elBanquos christmas light_MK1.fzz]
2022-11-21 Refactor colormap to integer values (not tested yet), Adapt documentation to sensor concept
    [elBanquos christmas light_MK1.fzz]
2022-11-21 Added calibration mode
2022-11-27 Added Button Panel Print, enhanced light sensor detection (denoise, higher resolution)
2022-11-27 Placed light sensor elements in circuit
    [elBanquos christmas light_MK1.fzz]
2022-12-30 Platine und erster Rahmenzwischenstand
    [elBanquos christmas light_MK2.fzz]
2022-12-30 Frame is now a person with a skirt
2022-12-30 Marking of drills half done
2022-12-30 All wiring complete
2023-01-03 Adapted code for PCB optimized pinout
    [elBanquos christmas light_MK2.fzz]
2023-01-03 #24 solved: Dailight mode will check every 60 seconds
    [ChistmasLights.ino]
2023-01-03 solved #27:reduced runtime of "sunflower" firework
    [firework.ino]
2023-01-03 Added power consumption documentation (#21)
2023-01-03 Refactore select button to "mode" button in function names
2023-01-16 Tuned the fireworks, (Sun less intense light, shorter pause, Joker faster, Rocket with some delay in phase 2, Glitter bomb more often but only 2 shots)
    [ChistmasLights.ino, firework.ino, particle.cpp]
